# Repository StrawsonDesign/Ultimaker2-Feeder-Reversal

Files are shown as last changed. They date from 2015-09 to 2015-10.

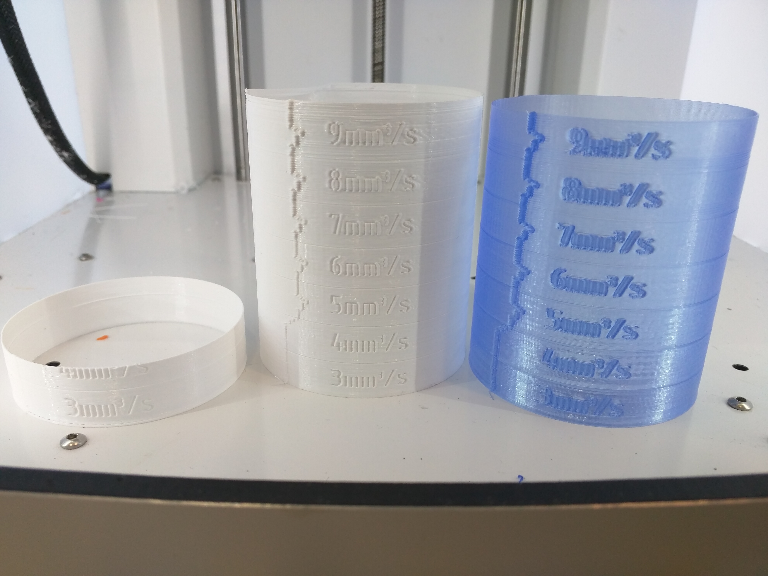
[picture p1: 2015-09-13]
Pictures/Speed_Improvement_Test.jpg

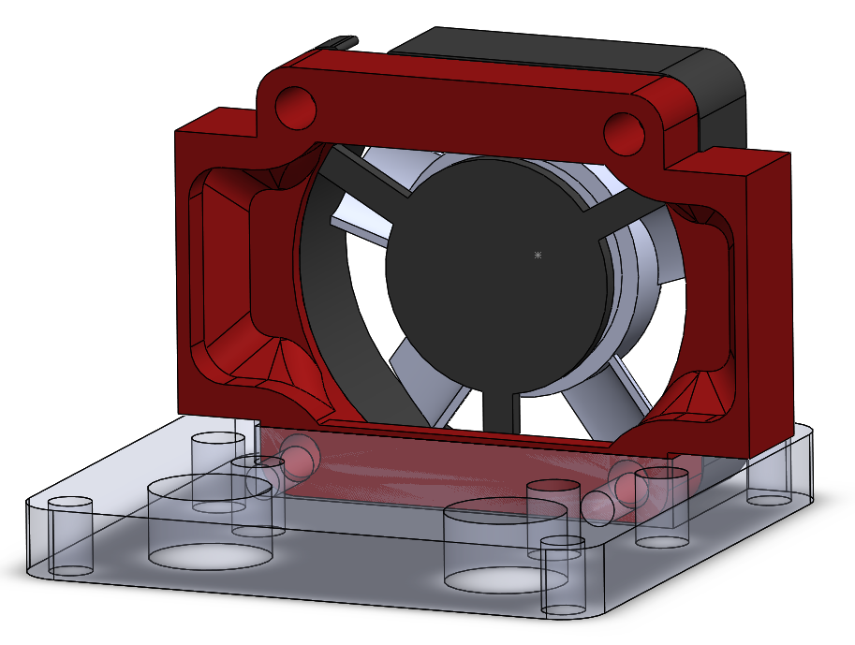
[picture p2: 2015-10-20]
Parts/Fan Duct/fan duct cad.PNG

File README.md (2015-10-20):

This repository contains all of the hardware and software modifications
we have made to our two Ultimaker 2 printers.

Included here is a fork of the Ultimaker 2 marlin firmware with the
necessary tweaks needed to complement the hardware tweaks.

See 'Ultimaker 2 Experiences and Modifications.pdf' for a detailed
outline of all the the modifications. The CAD files for the described
hardware mods are in this repository along with pictures of the
installation. 

See Strawson's 'Ultimaker Settings.fff' for the SImplify3D settings we
use with this configuration.

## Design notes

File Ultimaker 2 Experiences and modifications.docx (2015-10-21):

# Ultimaker 2 Experiences and Modifications

James Strawson 2015

University of California, San Diego

In April 2015 we took delivery of two brand new Ultimaker 2 desktop 3D printers to complement our overworked large-format printer. Our first impressions were positive. We enjoyed the clean user interface, solid construction, and especially the low-inertia X & Y axis mechanism. It is now October 2015 and we have put over 2000 hours of printing on each of them along with countless rebuilds. Along the way we have come to appreciate the many strengths of this design which have no-doubt been a result of the extensive testing and hacking of the original Ultimaker design by the open-source and DIY community. However, there are a couple of minor design faults which render the Ultimaker 2 unreliable and frustrating in a professional setting. Luckily these faults are cheap or free to remedy. In this paper we outline the various quibbles we have with the design of this printer and the steps we’ve taken to improve the performance and reliability. Along the way we will provide empirical test data to demonstrate the improvements along with discussion on our own failures along the way.

To help understand the component names used in this paper it is helpful to reference the Ultimaker 2 hardware documentation repository here https://github.com/Ultimaker/Ultimaker2.

## Thermal Improvements and Jamming

First I would like to start with a basic truth that explains the problems most people have when extruding PLA which has become the most popular plastic among the desktop 3D printer community. Within the hot end of every filament-fed FDM printer is a temperature gradient along the axis of the filament tube where the plastic transitions from solid to liquid. It is important that this gradient is as sharp as possible otherwise the filament will soften and expand under pressure to touch the inside of its guide tube. Usually this premature softening results in what we call jamming which is where the additional friction overcomes the feeder motor’s strength and plastic is no longer extruded consistently. In extreme cases the filament completely seizes in the hot end and must be melted out or forcefully removed. PLA suffers from jamming much more readily than ABS due to its lower melting temperature. This is not to be confused with clogging which is where a physical obstruction gets lodged in the small nozzle opening.

To keep this temperature gradient as sharp as possible, most hot ends employ active cooling in the form of a heatsink and fan right above the extruder nozzle and heater block. We have extensive experience with both the E3D V6 hot end and the Ultimaker 2 hot end, both of which have active cooling, and neither of which implement it properly. The E3D V6 includes a nicely designed heatsink with a ducted fan that ensures plenty of directed airflow over the heatsink fins. Sadly it is rendered mostly useless since the only surface contact the heatsink has with the heat break tube is a loose thread. The solution is simple: to fill the gaps of the thread with copious amounts of thermal paste. As an added measure we also heat up the aluminium heat sink with a hot air gun to about 150C before tightening the stainless steel heat break in place. When the heatsink cools it locks the threads tightly together preventing them from loosening during operation which would break what little thermal contact there is. I have added this procedure to the E3D wiki and have received considerable response from the online printing community confirming its effectiveness.

The Ultimaker 2 demonstrates the same thermal issue. About 40 minutes into a print we would consistently notice jamming and the part would be a complete failure. The problem is that the active cooling on the Ultimaker is not as active as you would think. The included 25mm 5V cooling fan is reasonably powerful, but is mounted flush against the heatsink in such a way that air is only allowed to flow through two of the eleven slots. To remedy this we designed a duct that spaces the fan 6mm back from the heatsink and allows airflow through all of the slots. This had the added bonus of reducing the noise generated by the fan for two reasons. Firstly the fan spins slightly slower based due to not being stalled from lack of airflow. Mostly the reduced noise is because the fan no longer rattles against the heatsink. The thermal performance gain from the duct immediately solved the jamming issue and we can now successfully complete >24 hour prints without overheating or jamming. The file for this duct is available on our GitHub repository linked at the end of this document.


The Ultimaker factory uses copper grease between what they call the hot end isolator and the hot end holder bottom mount. This is very wise for two reasons. Firstly it provides lubricant for this part when it is turned for adjustment, and secondly it provides a necessary thermal interface to transfer heat from the isolator to the heatsink. Without it, jamming will occur even with the cooling duct. Normal CPU thermal paste seems to work equally well and we suggest cleaning the interface and reapplying thermal paste every time the isolator is removed.

Once the heat has transferred from the hot end isolator to the bottom hot end holder, it must still transfer to the heatsink. However, the bottom of the heat sink is very rough on both of our models and looked to be machined with a dull end mill without a finishing pass. For good measure, we also applied thermal paste between the heatsink and the bottom hot end holder to improve this necessary thermal contact. We cannot confirm if there is a real performance improvement from this as the duct solved the jamming issue completely. However, thermal paste is cheap and application is easy since you must disassemble the hot end assembly to apply the remainder of these modifications anyway.

## Friction Reduction and Feeder Reversal

With the duct installed and thermal paste applied, you should finally be able to print larger parts without jamming. Sadly, you will also discover that printing any faster than 20mm/s at standard 0.1mm layer heights will result the feeder motor skipping steps. Regardless of how slowly we printed, we found that plastic would extrude very inconsistently and while parts may look alright, they would lack structural integrity and are therefore useless for engineering prototypes. This is what the Ultimaker community calls underextrusion which is caused by friction and rough passage of the filament through the Bowden tube while under pressure.

We give credit to YouMagine member Pikita for providing a volumetric speed test for the Ultimaker that slowly ramps up the extrusion rate from 3mm^3/s to 10mm^3/s to measure the limit of the printer. This part is available here https://www.youmagine.com/designs/test-print-for-ultimaker--2. There is also a lengthy community discussion here: https://ultimaker.com/en/community/view/5586-can-your-um2-printer-achieve-10mm3-s-test-it-here. From reading this thread we gather that factory-spec Ultimaker 2 printers vary greatly in the speed they can achieve and that many struggle to achieve 4mm^3/s even when running the hot end much hotter than normal at 230C. The creator of this test recommends running this test at a nozzle temperature of 230C but we find this a little unrealistic for PLA prints as that temperature will quickly cause plastic degradation and carbon buildup in the nozzle. We personally have found 210C to be the ideal PLA temperature on both our Ultimakers from the perspective of both extrusion consistency, layer bonding, and surface quality. However, neither of our Ultimakers could reliably extrude even 3mm^3/s at 210C so we kept with the recommended 230C for the time being.

As a quick experiment we added a thin coating of oil to the inside of the Bowden tube. Immediately the printer was able to extrude at 4mm^3/s. This slight but distinct improvement was evidence enough for us to pursue more permanent friction reduction methods. We do not recommend oiling the tube whatsoever as it quickly resulted in gunky buildup on the inside of the nozzle.

The standard feeder arrangement and spool holder places the knurled feeder wheel on the outside of the natural bend of the filament. Since the knurled feeder wheel is of particularly poor design it chews up the filament where it is in contact, especially if the part requires a lot of filament retractions. The filament twists such that its natural bend matches that of the Bowden tube. The friction of the chewed-up side of the filament against the inside of the entire feeder system when under pressure has proven to be the single largest contributor to poor performance. Luckily the entire filament assembly is reversible which places the smooth unmolested side of the filament in contact with the Bowden tube while under pressure.

All that is necessary is to remove the 2 M3 screws holding the left motor cover on and the 4 M3 screws holding the feeder mechanism to the back of the printer. After screwing the feeder mechanism back on in reverse, it is then necessary to reverse the direction of the feeder motor to compensate. This is a quick adjustment in software. At the end of this paper you will find a link to our GitHub repository with this and other necessary changes. With this change implemented, the friction of the filament through the entire mechanism was reduced so greatly that our volumetric speed test was now capable of printing 9mm^3/s at 230C, a threefold increase from the factory configuration. We confirmed this on both printers with both white and blue filament to be certain. Here are pictures of both the new feeder orientation and the new test pieces demonstrating the speed improvement.

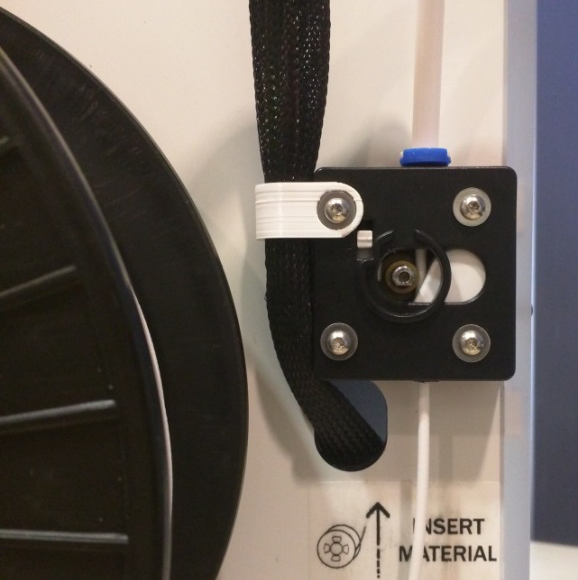
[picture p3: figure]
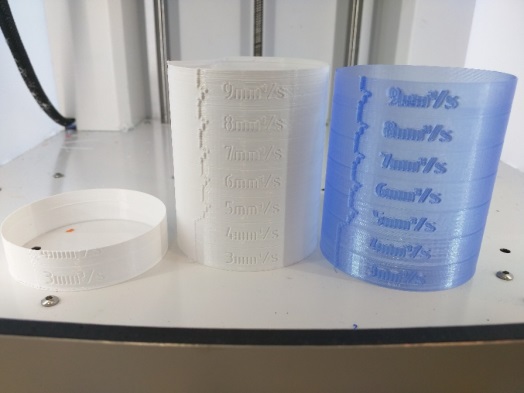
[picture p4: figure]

## Hobbed Wheel Upgrade

Even with this large reduction in friction, we wished to replace the poorly designed knurled feeder wheel with something that would both be less likely to grind straight through the filament and would reduce the slight slipping that results in inconsistent filament feed rate. We found that the hobbed feeder wheel design from the RepRap Mendel open source printer was a perfect fit on the Ultimaker 2 and resulted in much improved performance. This part is available from many sources on the internet, but we purchased ours from the Signwise here: http://www.amazon.com/gp/product/B00XP3NJSE?psc=1&redirect=true&ref_=oh_aui_detailpage_o01_s01.

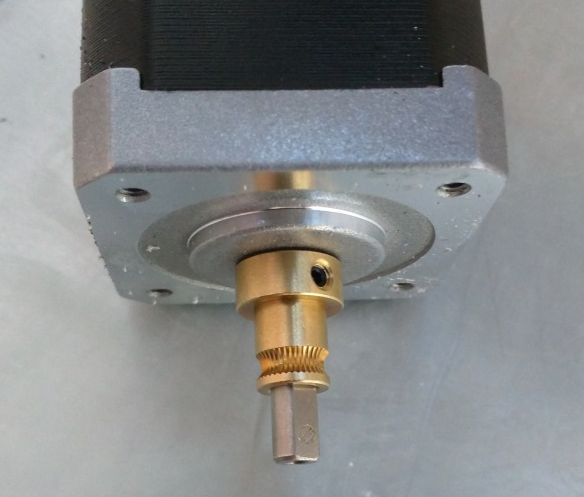
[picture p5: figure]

Instead of a sharp knurled surface which tends to wear away at the filament, this hobbed wheel actually wraps around the curvature of the filament providing much more surface contact and improved grip. Since it wraps around the contour of the filament it is possible to apply much more spring preload to the feeder bearing reducing the likelihood of slipping when the printer inevitably jams or clogs. We found that mounting it on the feeder motor shaft with 0.5mm clearance to the motor housing gave the correct offset to center the filament in the feeder mechanism. The above picture demonstrates correct mounting orientation.

The smaller diameter of the hobbed wheel means that it is necessary to run more spring preload in the feeder mechanism to achieve the same pressure. The Ultimaker manual suggests running as little preload as possible because any more will simply increase the rate at which the standard knurled feeder wheel chews through the filament. The hobbed wheel does not suffer from this problem and we can take advantage of higher pressure to reduce the chance of slipping. We have found that setting the preload at the second notch from the bottom is sufficient.

The new hobbed wheel measured 6.7mm diameter at its smallest point. The knurled wheel measured 7.9mm so we started by adjusting the steps/mm by the ideal ratio. The default is 282.

282*7.9/6.7 = 332.5 steps/mm

To test, we set the extrusion multiplier in our slicer to 1.00 and printed 20mm test cubes at solid infill to determine the exact steps/mm constant that gives us the best result. We did this process in parallel with both of our printers, one running undersized filament and the other running oversized filament. In both cases we did measure the filament diameter across a few points and entered this into the slicer. This tuning process is particularly important because there is less slip with this new feeder arrangement and slip is also a major contributor to the real-world feed ratio. The distance the knurling sinks into the filament and measurement error will make a difference. The ideal ratio of 332.5 was close, we experimentally found 327 steps/mm to give the best results on both printers and both filaments. The final change can be seen in our GitHub repository.

We were pleasantly surprised to see our experimentally determined steps/mm was within one percent of the calculated value. With the standard knurled wheel we had to run a 1.04 extrusion multiplier even when printing slowly and 1.08 when pushing as quickly as possible. With the new hobbed feeder wheel 1.00 gives us ideal results regardless of printing speed. This indicates considerable slip with the original feeder wheel.

## Increasing Feeder Motor Torque

The smaller diameter of the hobbed applies more linear force to the filament for the same feeder motor torque. The added grip of the hobbed wheel also allows us to increase the feeder motor torque without fear of chewing through the filament. Now we sought to achieve the highest feed extrusion rate possible while printing at the more realistic temperature of 210C since we almost hit the 10mm³/s limit at 230C.

When the Ultimaker 2 was first released the feeder current was set to 1350ma from the factory. A recent software update reduced that to 1250ma in an attempt to reduce the number of user complaints of chewed filament. We actually increase this to 1500ma to increase the total available torque available. Even at this higher current, the stepper will still skip as a failsafe before the hobbed wheel slips on the filament. While the stepper driver ICs are rated for 2000ma the Ultimaker control board is not designed with sufficient cooling and we hit the thermal protection safety at 1700ma.

We attempted to disable microstepping in hopes of gaining a bit more torque but this seems to be hardwired on the control board as firmware changes had no effect.

Before increasing the stepper current we were able to print 9mm3/s successfully at 230C but only 6mm/s at 210C. With the current increased to 1500ma and microstepping disabled we can now easily extrude 10mm3/s at both 230C and 220C. The 220C test pic pictured below on the left. Finally we can consistently extrude 8mm3/s at 210C as pictured below and on the right. Note that the 9mm3/s level is underextruded but still holds together without complete structural failure.

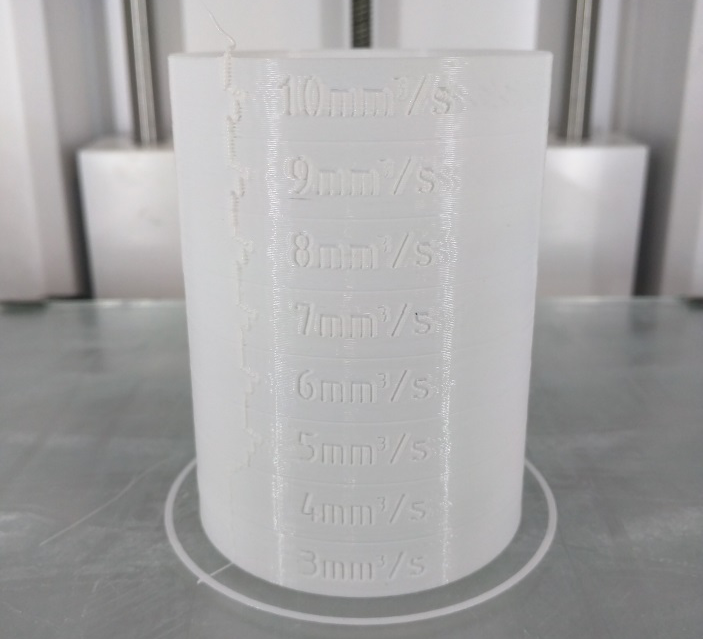
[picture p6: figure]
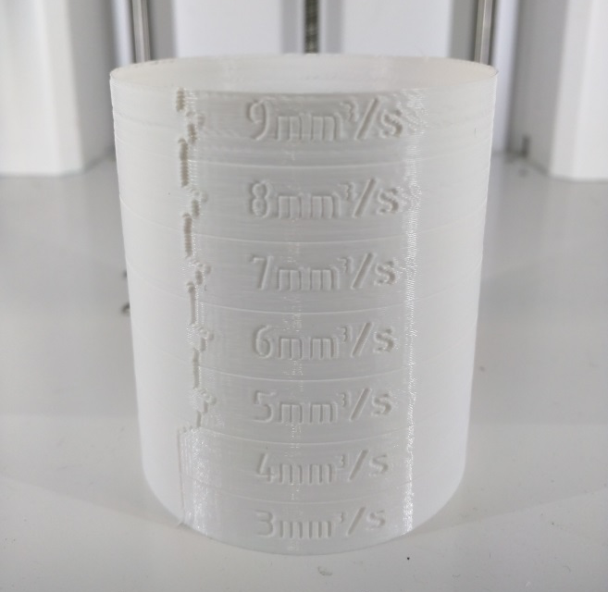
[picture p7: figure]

## Filament Guide and Spool Holder

During this tuning process we were also very careful to measure the filament diameter and make the appropriate change in our slicer settings for every test. We also noticed that the angle at which the filament entered the feeder make a slight difference as well as the bend radius of the filament. Thus, we pursued a filament guide setup that would provide more consistent results. The main improvement was installing a ball-bearing mounted spool just beneath the feeder mechanism using an existing hole that is used for the motor cover. In this convenient position the filament now feeds straight into the feeder mechanism instead of being tugged at an angle. While we were making improvements, we also made a second ball-bearing guide to replace the standard black plastic guide which had worn straight through as the filament simply grinds against it.

These spools are available on our GitHub along with the other components here. We designed them with a probably unnecessarily large flange to help keep the filament from slipping off when shifting the printers around or when the spool gets nudged. After two failed prints due to the filament slipping off the guide we arrived at this solution and have not had a single failure since.

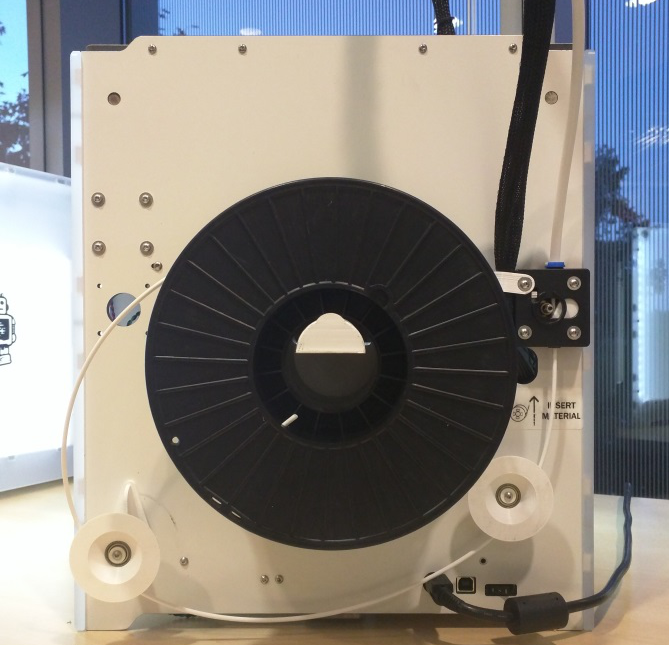
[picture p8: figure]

The standard spool holder also bothered us. Firstly it squeaked badly, and secondly its diameter was so large that most of our spools would not fit. YouMagine community member Solonari designed a very nice replacement that solves both of these problems as is available here: https://www.youmagine.com/designs/ultimaker-2-36mm-spool-holder-v1-2. We found that the small tab stopping the spool from sliding off was a little too small and broke easily so the version on our GitHub repository is strengthened.

YouMagine user Izzy also designed a nice clip to hold the Ultimaker wiring harness out of the way of the filament and the moving spool. There is no performance improvement to be had but it keeps the back of the Ultimaker neat and tidy and is well worth the 10 minutes it takes to print the part. It really bothers me that the wiring harness rubs against the filament from the factory. Reversing the feeder mechanism keeps this from happening but the harness still rubs on our larger spools so I highly suggest using Izzy’s design available here: https://www.youmagine.com/designs/wire-retainer-clip.

We only use one of these on each printer and mount it on the top left corner of the feeder mechanism when looking at the back of the printer. It can be seen in the previous pictures.

## Bowden Tube Replacement

We quickly discovered that the Ultimaker struggled to print in the back left corner of its print bed. This became very frustrating when printing large parts and batch prints. If one pays for a 23x22 cm bed then one should expect to be able to use all of it. The cause of this issue is that when printing in that far corner the Bowden tube is bent at a very tight radius. We sought to find a slightly longer tube which would be a drop in replacement and also provide less friction if possible.

Fluorotherm 1/8” ID PTFE tubing is a perfect fit for the Ultimaker Bowden clips. We ordered a 5 foot length and found that the 2.5 foot length achieved by cutting it in half was about 140mm longer than the Ultimaker Bowden tube. This was just enough added length to achieve consistent performance across the entire print bed and the tube has visibly less bend. Sliding the filament through by hand takes less effort than the standard Bowden tube also. This tubing is available here: http://www.amazon.com/gp/product/B00KJDE67G?psc=1&redirect=true&ref_=od_aui_detailpages01.

It is necessary to modify the tube stock slightly before installing it just like Ultimaker does. The feeder end needs to be countersunk at a 45 degree angle to allow new filament to feed in without catching on the edge when changing spools. It is also necessary to drill out the inside of the other end about 3cm deep with a 3/16” drill bit to prevent hot plastic from sticking to the inside when the printer retracts the filament after every print. We also beveled the outside edge of both ends of the tube to make inserting into the Bowden clips easier.

If your printer has been used a lot you may notice the tube has started to wobble in the clips slightly. The more play in the Bowden clips then the more retraction distance is necessary to both relieve the pressure off of the compressed filament and pull the filament back out of the nozzle slightly. The brand new tube should fit snuggly in the clips with zero movement up and down. The filament compresses significantly inside the tube when extruding quickly under pressure and the longer tube only increases this. Luckily the new hobbed feeder wheel allows us to use high retraction distances without chewing up the filament. We like to use 6.0mm of retraction and have found no reduction in stringiness by going higher.

The final modification that must be done to compensate for the longer tube is to increase the distance that the feeder pulls the filament out when changing filaments. This constant is called BOWDEN_FILAMENT_LENGTH in the firmware source code and we increased this distance from 705mm to 840mm in our GitHub Repository fork of the firmware.

## PTFE Isolator Coupler

About 500 hours into printing each of our Ultimakers demonstrated a sudden drop in performance. Furthermore, the filament would jam in the bowden tube after every print and would require manual removal and trimming. The reason for this is that the PTFE Isolator Coupler deforms over time from the heat of being in contact with the heater block. Ultimaker now consider this to be a wear item and charge $20 for a replacement.

Ultimaker community member Olsson designed and now sells a resilient insulator which installs between the heater block and the standard PTFE Isolator Coupler to extend the life of the coupler. This is called the I2K insulator as is available in Europe here: http://3dsolex.com/i2k-insulator. If you are in the US then community member GR5 sells these same parts at his store here: http://gr5.org/store/index.php/um/i2k-insulator.html. GR5 also sells the replacement isolator couplers for roughly half the price of the Ultimaker OEM replacement parts and they work equally well from our experience. GR5 is a helpful contributor to the Ultimaker 2 community and was one of the first people to be able to print at 10mm^3/s.

Olsson rightly suggests adjusting the height of the heater nozzle to be as high as possible by threading the steel hot end isolator all the way onto the heater block then backing off a quarter of a turn to prevent unnecessary thermal contact with the threads. This puts as much spring pressure as possible on the PTFE Coupler and I2K Insulator to prevent leaking. It also raises the PTFE coupler higher up into colder region of steel hot end isolator to reduce its temperature and make the part last longer. This may also serve to increase the temperature gradient as discussed in the thermal section of this paper but this is difficult to measure. Another benefit it that this prevents the heater block from touching the steel cooling fan duct which ours did from the factory. In addition to the loss in efficiency, we also found that the nozzle would drop in temperature by over 10 degrees as soon as the cooling fans turned on before the feedback controller brought it back up. With the added clearance this no longer occurs.

## Nozzle Cleaning

Every time we change filament colour we perform a cold pull to clean out the nozzle. We will also do this before rebuilding the hot end to remove all traces of plastic from the PTFE isolator coupler and the heater block. We credit the procedure to Ultimaker forum member MostlyAtomicBob and is well documented here: https://ultimaker.com/nl/support/view/149-atomic-method. For the Ultimaker, our exact procedure is as follows:

1. Remove the Bowden tube from the top of the hot end.
2. Manually set the nozzle temperature to 210C in the Ultimaker 2 advanced menu.
3. Insert a piece of scrap white PLA into the nozzle which is at least 300mm long.
4. Press the filament in firmly and extrude about 40mm of filament to flush out old plastic.
5. Set the temperature to 75C and keep pushing filament through as it cools.
6. At around 110C the chance of air getting in is minimal and you can let go while it keeps cooling.
7. After it has settled at 75C for a couple minutes, tug the filament out quickly.
8. Make sure the hot end isolator has seated back into its groove in the bottom hot end holder. If it hasn’t, wiggle it back into place with a 2.5mm hex key.
9. If the white PLA pulled out a significant amount of black crud from the inside of the nozzle then repeat the process.

Turning the knob continuously to set the temperature can be rather annoying. YouMagine member Swonkie has designed a fantastic replacement knob available here: https://www.youmagine.com/designs/ultimaker-2-knob--2. This is a very nice touch to the printer and makes removing the knob easy if you want to keep people from fiddling with it during a print such as at trade shows.

## Retraction and Wipe Setting

With less play due to the nice new bowden tube we wished to retune the retraction distance that is just enough to stop stringiness. For this test we printed in parallel a 20mm cube along with nine 4x4x20mm columns so there would be plenty of retractions along with big and small islands to make sure extrusion was consistent across the whole print bed.

We started with the retraction settings that worked well for us with the default configuration: 6mm retraction, 0.5mm coast, and 2mm wipe. This was done using Simplify3D 3.0.2 for our slicer. We actually found that only 3mm retraction was now sufficient. Since Simplify3D now supports gentle retraction while wiping we increased the wipe to 3mm so the print head wouldn’t need to slow down as much for the wipe. We then quickly discovered that prints would underextrude in areas with multiple islands. Disabling the coast feature helped this slightly as plastic no longer stops extruding right at the end of each loop. The result was that all 9 thin columns and the 20mm cube would print completely solid with no skipped layers and each stood up to a quick bend test by hand. Previously parts with skipped layers would simply fall apart in your hand.

We finally discovered that while that test print worked perfectly, other real parts would still cause extruder jamming and underextrusion in areas with lots of islands. This appears to be a bug with simplify3D 3.0.2 as reported here https://forum.simplify3d.com/viewtopic.php?f=9&t=3536. The solution was to check the box for relative extrusion.

## Software Changes

The following software settings changes were necessary:

- Reverse feeder motor direction on line 325 of Configuration.h

#define INVERT_E0_DIR true

- Increase feeder motor current to 1450ma on line 207 of Configuration_adv.h

#define DEFAULT_PWM_MOTOR_CURRENT {1200, 1200, 1500}

- Change feeder motor steps/mm on line 366 of Configuration.h

#define DEFAULT_AXIS_STEPS_PER_UNIT {80.0,80.0,200,327}

- Increase retraction length when changing filaments on line 385 of Configuration.h

#define FILAMANT_BOWDEN_LENGTH 840

Much to our frustration we found that the feeder motor current and motor steps/mm are read in from the EEPROM on startup instead of from the firmware binary itself. Only after performing a factory reset do these changes take effect. Since we wished to flash new Ultimakers in one step we also added the following lines to the very end of the Config_RetrieveSettings() function at line 241 of ConfigurationStore.cpp to ignore what’s in EEPROM and load our new default settings instead.

//ignore EEPROM extruder steps/mm and current

float temp1[]=DEFAULT_AXIS_STEPS_PER_UNIT;

axis_steps_per_unit[3]=temp1[3]; //overide EEPROM steps

float temp2[]=DEFAULT_PWM_MOTOR_CURRENT;

motor_current_setting[2] = temp2[2]; // overide EEPROM current

## Failed Experiments

We have tried a couple of unsuccessful modifications which we would like to share with you here anyway. Our first attempt at fixing the underextrusion issues was to try the very popular replacement feeder by YouMagine user IRobertI here:https://www.youmagine.com/designs/alternative-um2-feeder-version-two.

It is nicely designed and we loved that it includes a quick release to pull the feeder bearing away and allow manual removal of the filament when the knurled feeder wheel grinds through the filament or gets jammed. However, it doesn’t offer any performance improvement nor does it address the fundamental problem with the feeder which is the knurled wheel itself. It also cannot be installed in reverse which is what helped us reduce the friction in the Bowden tube.

We also tried the fan ducts designed by YouMagine user mnis available here: https://www.youmagine.com/designs/ultimaker-2-cpv9. We loved that it allows you to throw away the 12 screws holding the cooling fans and the original duct in place which makes rebuilding the hot end much faster. We also love that it directs some of the cooling flow to the heat sink and the PTFE coupler which actually works so well that our previously discussed heat sink cooling duct was not necessary. In addition, the fans stick out less giving a few more millimeters of useable print bed on the right side. However, there are two issues. The small amount of plastic which is purged out at the beginning of every print is prone to getting caught in the ducts whereas the factory duct knocks that plastic off the side of the bed. More critically, when printed out of PLA these ducts tend to warp and sag after a couple hundred hours of printing. This was a neat experiment but there is really no reason to change the OEM cooling fan arrangement.

## Conclusion

To summarize we made the following hardware modifications in order of importance:

- Printed fan duct
- Feeder mechanism reversal
- New hobbed feeder wheel
- I2K insulator
- PTFE Bowden tube
- Ball bearing filament guide spools
- Thermal paste on heatsink and isolator
- Printed spool holder
- Printed control knob
- Printed wire clip

The combination of these small improvements has entirely fixed our complaints with the original Ultimaker 2 design. It can now extrude plastic over 3 times faster and with more consistency. Furthermore it is quieter when in operation and has not jammed or stripped the filament once since the modifications. Finally, we do not need to replace the PTFE coupler once every 6 weeks. None of these modifications were expensive or difficult, however the process was tedious and time consuming. We hope you, fellow Ultimaker 2 owner, can benefit from what we have documented here. We also thank Ultimaker for what we still consider to be one of the highest quality printers on the market but with the hope that these simple changes make their way into the OEM assembly procedure.

The CAD files and complete firmware source code required for the modifications documented here are all available here: https://github.com/StrawsonDesign/Ultimaker2_Mods

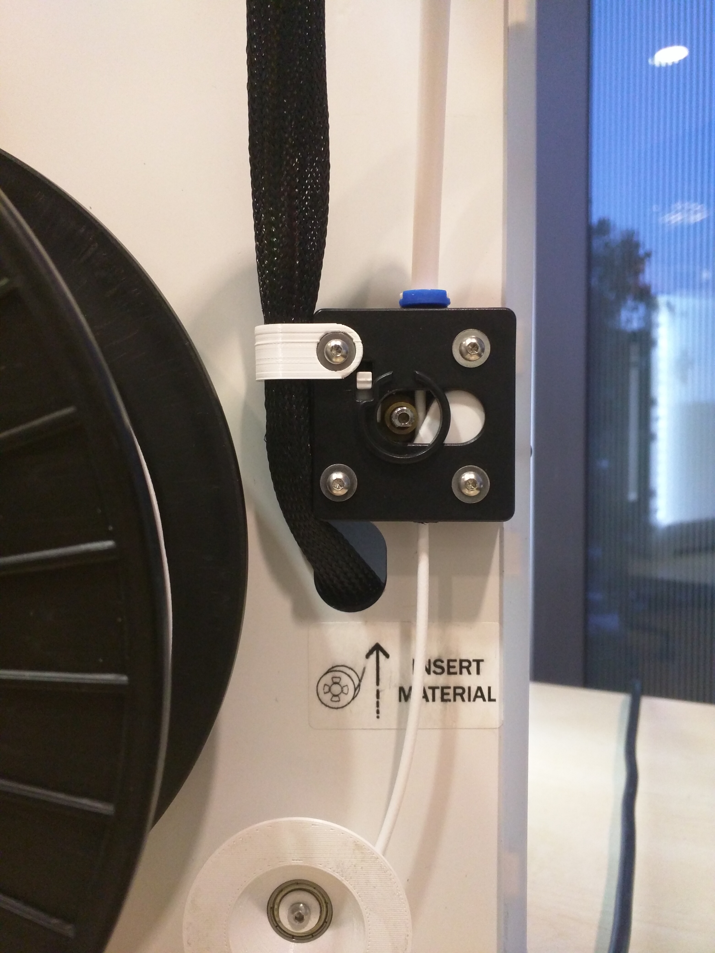
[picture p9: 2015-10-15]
Pictures/Feeder_Orientation.jpg

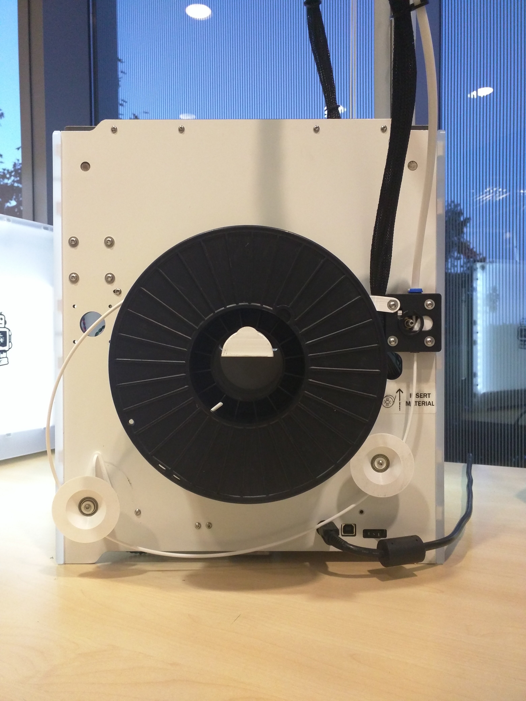
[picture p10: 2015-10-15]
Pictures/Ball_Bearing_Spools.jpg

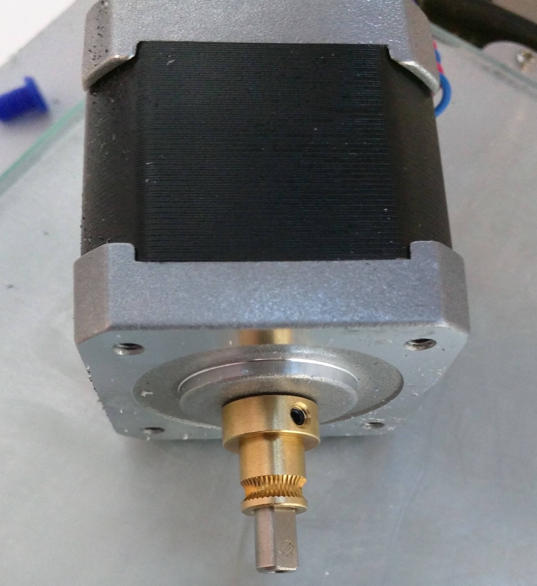
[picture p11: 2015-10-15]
Pictures/Hobbed_Feeder_Wheel.jpg

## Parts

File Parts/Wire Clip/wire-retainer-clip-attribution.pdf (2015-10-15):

# Wire Retainer Clip

by

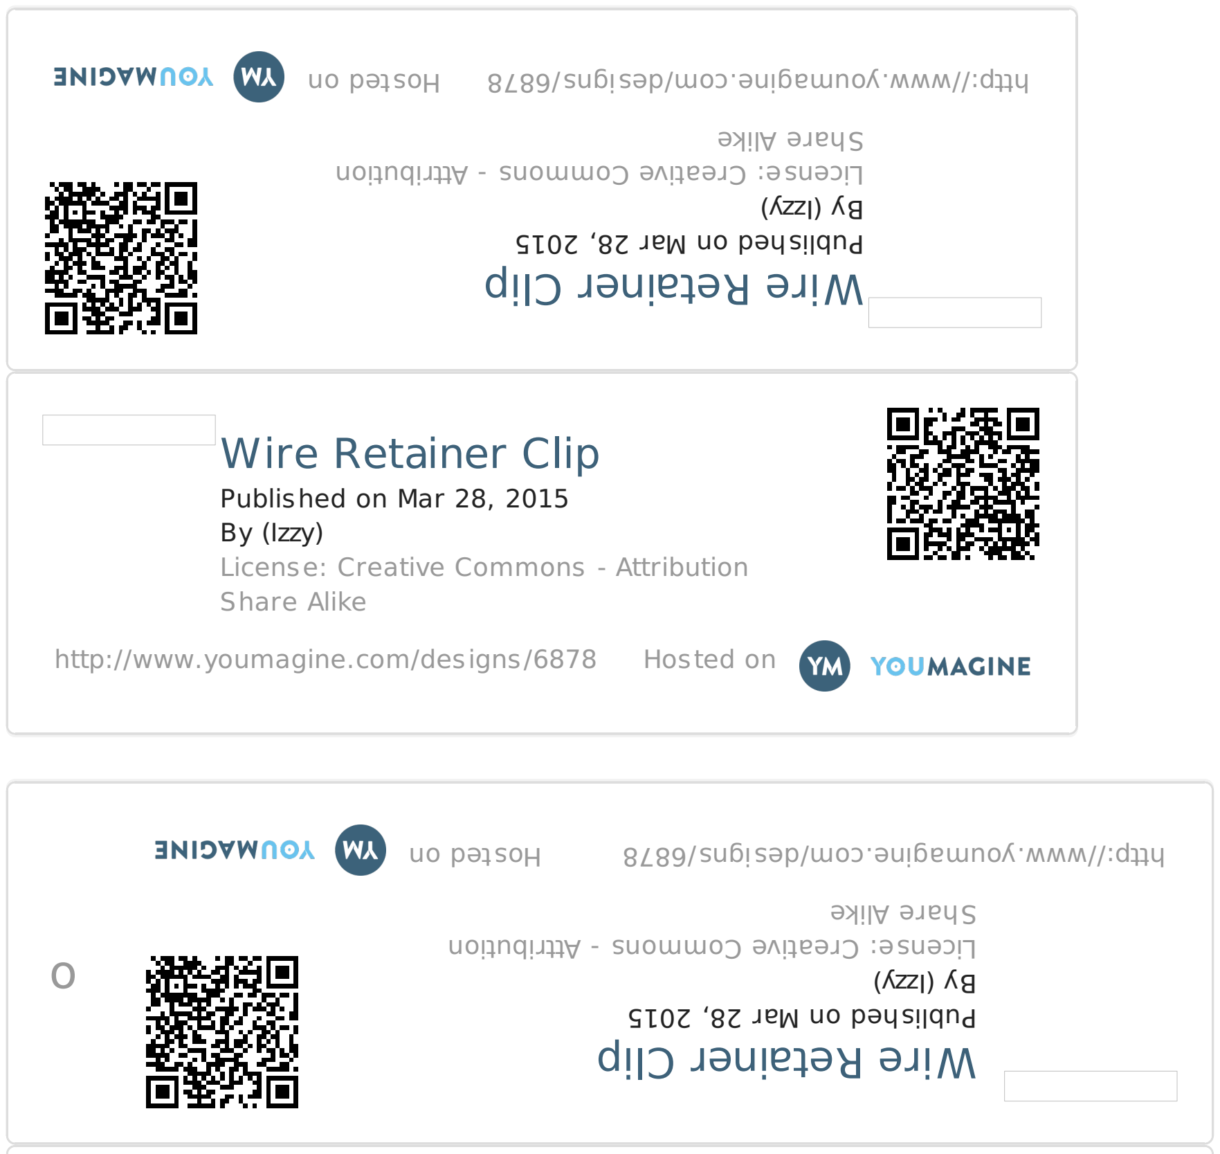
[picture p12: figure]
Wire Retainer Clip; Published on Mar 28, 2015 By (Izzy) License: Creative Commons - Attribution Share Alike; http://www.youmagine.com/designs/6878; Hosted on

o

## Wire Retainer Clip

Published on Mar 28, 2015
By (Izzy)
License: Creative Commons - Attribution Share Alike

http://www.youmagine.com/designs/6878 Hosted on

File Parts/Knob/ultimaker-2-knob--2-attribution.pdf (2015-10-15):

# Ultimaker 2 Knob

## By Swonkie

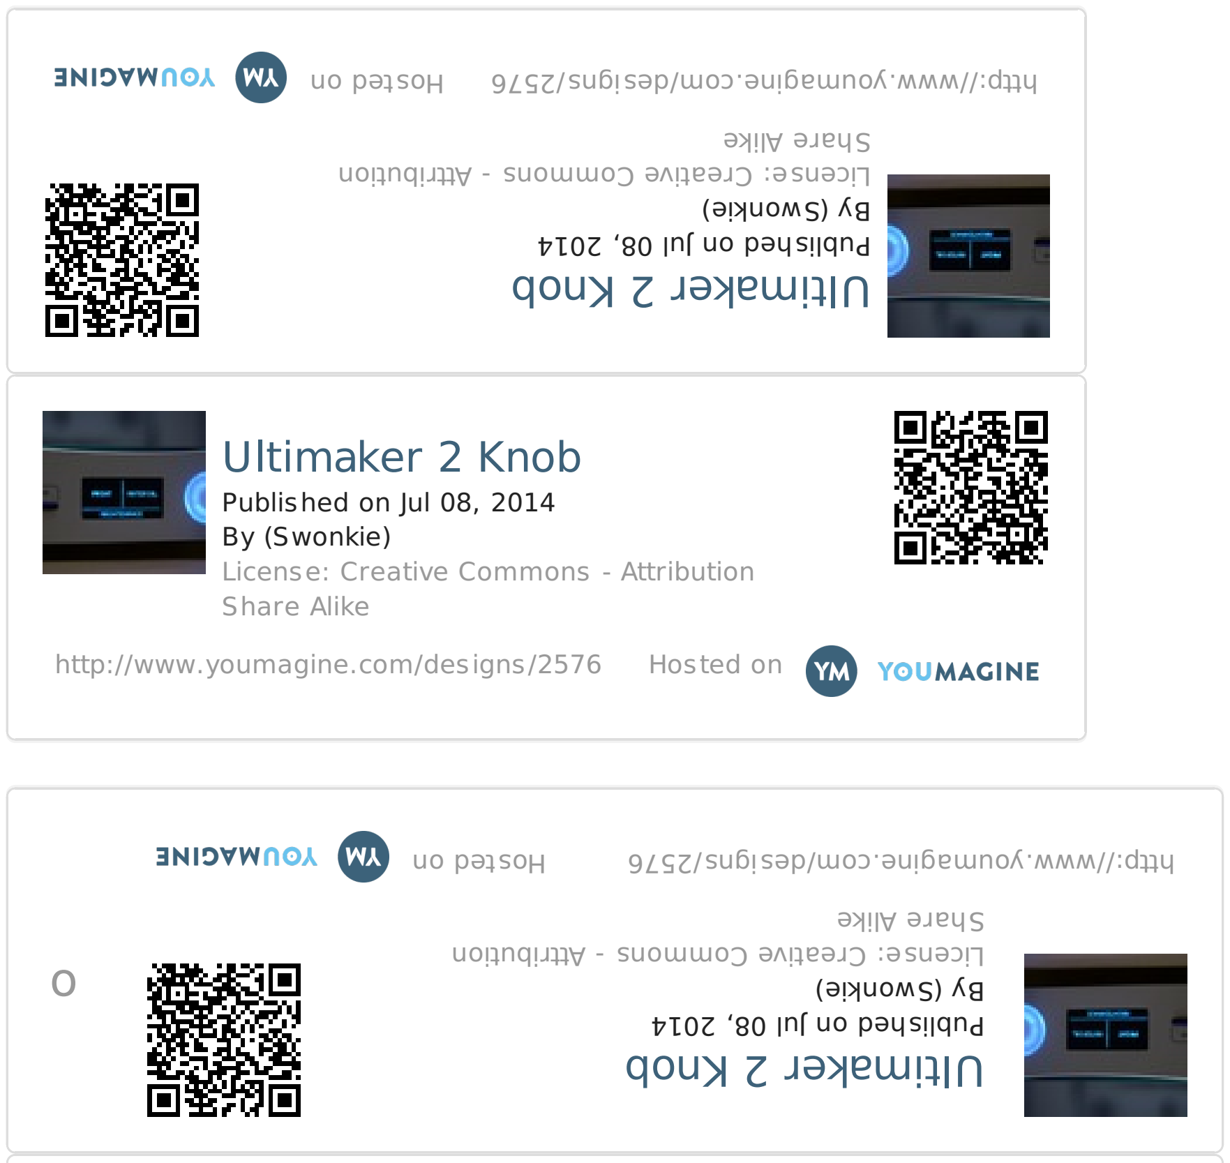
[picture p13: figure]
Ultimaker 2 Knob; Published on Jul 08, 2014 By (Swonkie) License: Creative Commons - Attribution Share Alike; http://www.youmagine.com/designs/2576; Hosted on

o

## Ultimaker 2 Knob

Published on Jul 08, 2014
By (Swonkie)
License: Creative Commons - Attribution Share Alike

http://www.youmagine.com/designs/2576 Hosted on

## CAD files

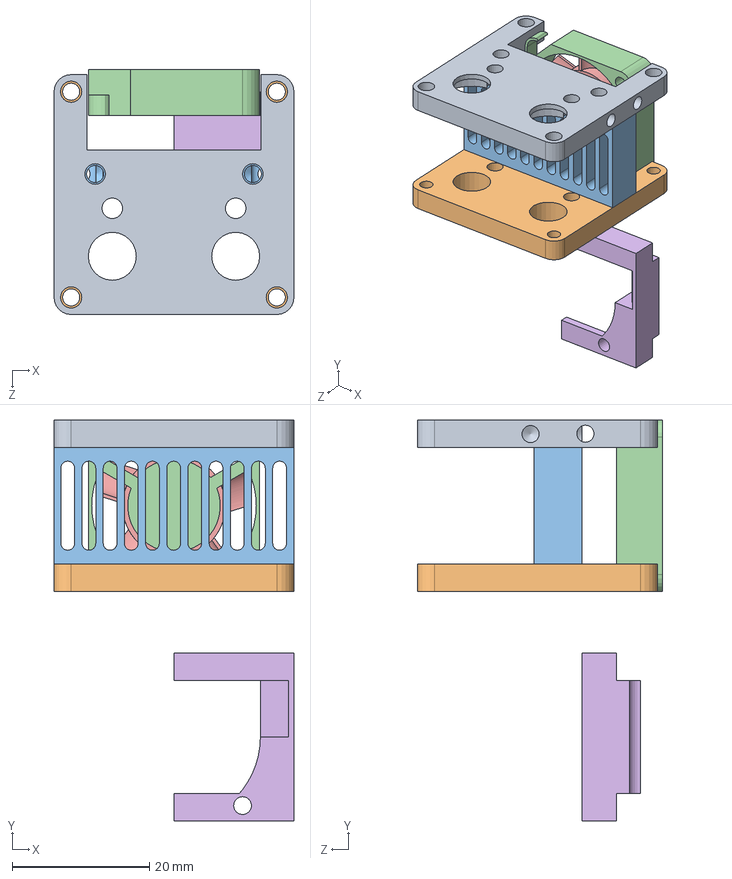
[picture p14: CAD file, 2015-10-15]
Parts/Fan Duct/solidworks assembly/fan duct assembly.SLDASM
35.0 x 58.5 x 35.8 mm
1307-Z2P-B Hot End Holder Top
1306-Z2P-B hot end holder bottom
1308-Z2P-B Cooling Rib Hot End
1330 Fan Base 25x25
DUct

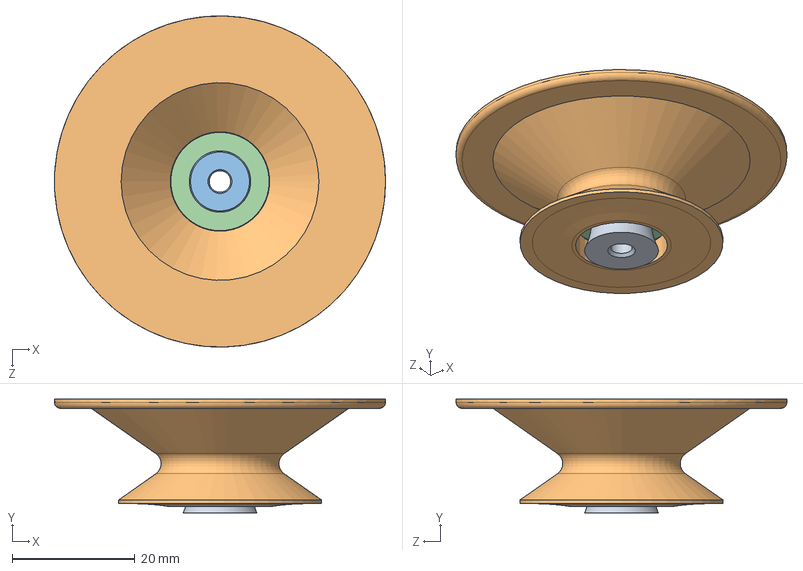
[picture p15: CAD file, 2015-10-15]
Parts/Bearing Filament Guides/Assem1.SLDASM
53.9 x 18.5 x 53.9 mm
standoff
outer guide
washer
bearing

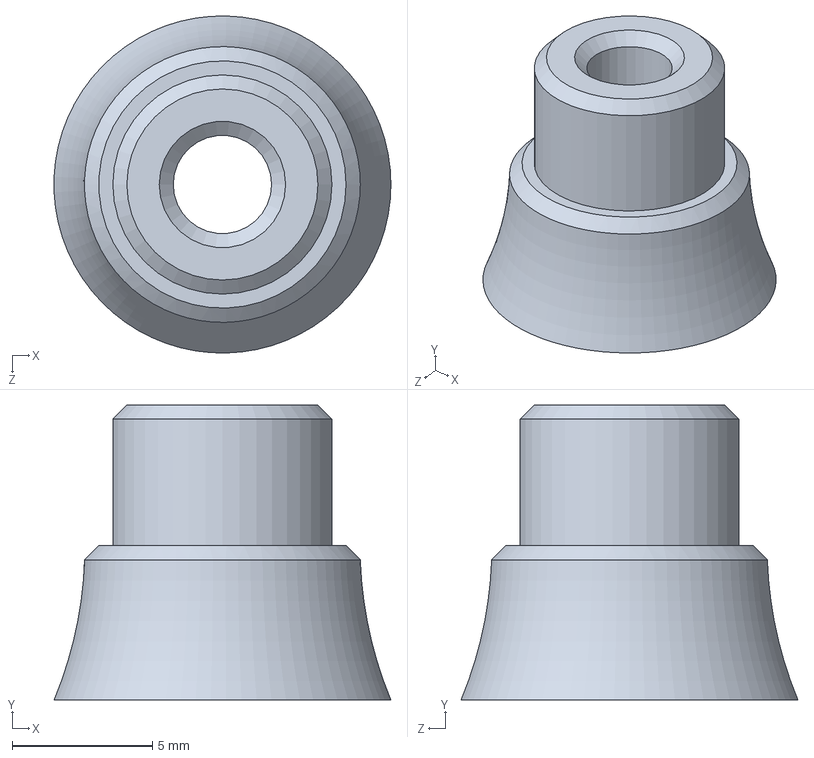
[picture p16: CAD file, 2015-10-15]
Parts/Bearing Filament Guides/standoff.SLDPRT
12.0 x 10.5 x 12.0 mm

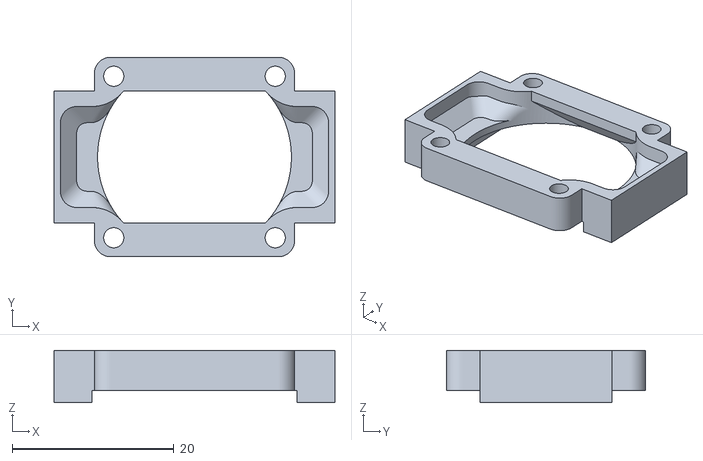
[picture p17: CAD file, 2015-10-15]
Parts/Fan Duct/Duct.STL
34.8 x 24.7 x 6.50

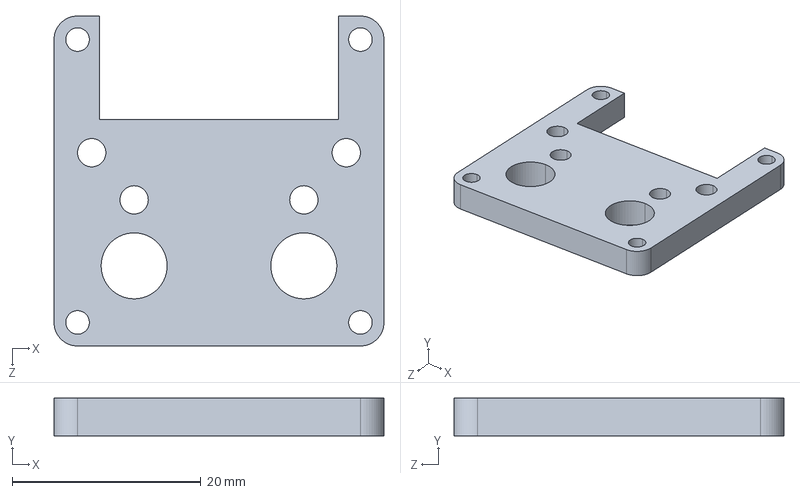
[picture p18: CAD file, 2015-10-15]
Parts/Fan Duct/solidworks assembly/1306-Z2P-B hot end holder bottom.STEP
35.0 x 4.00 x 35.0 mm

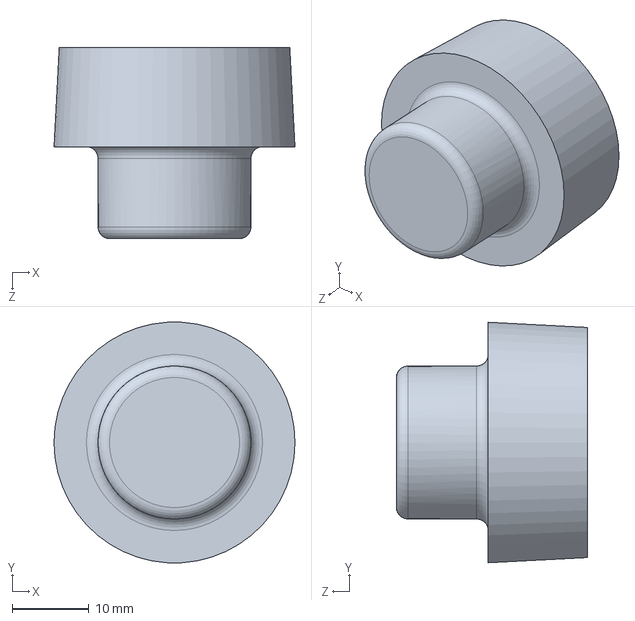
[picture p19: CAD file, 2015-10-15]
Parts/Knob/Knob.SLDPRT
31.5 x 31.4 x 25.0 mm

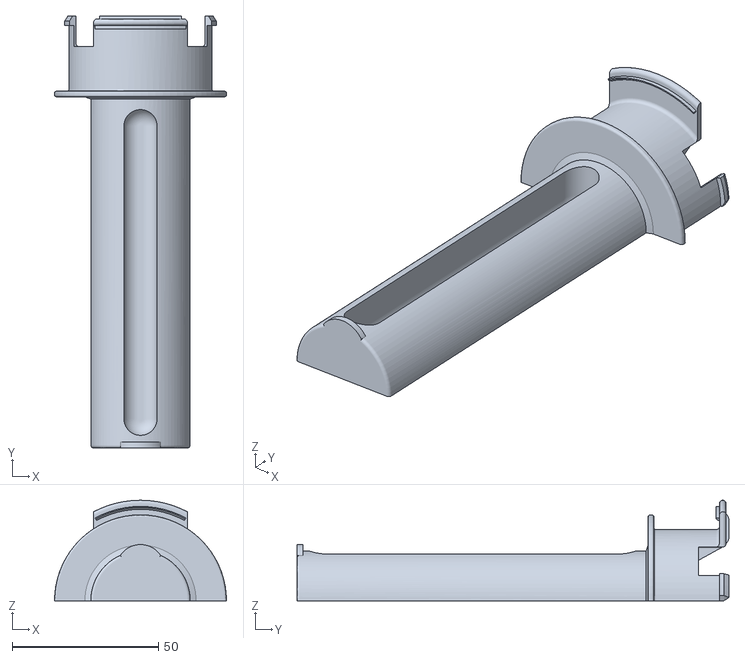
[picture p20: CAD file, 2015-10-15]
Parts/Spool Holder/Filament_Spool_Holder_v1_2 JS.STL
58.8 x 147.7 x 34.4

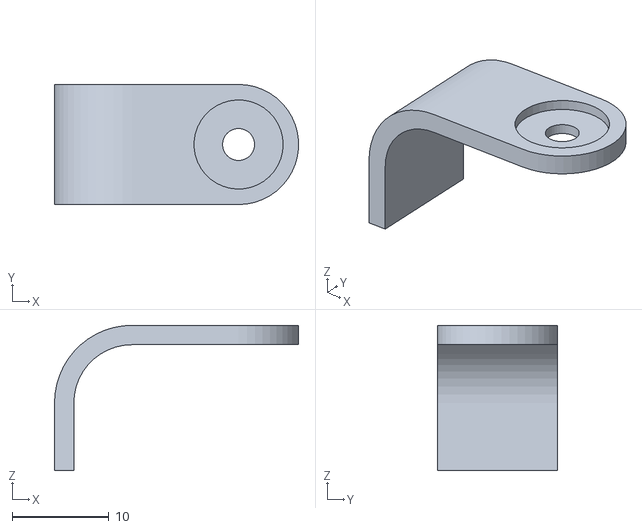
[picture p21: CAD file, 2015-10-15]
Parts/Wire Clip/Wire_Retainer_Clip.STL
25.2 x 12.4 x 15.0

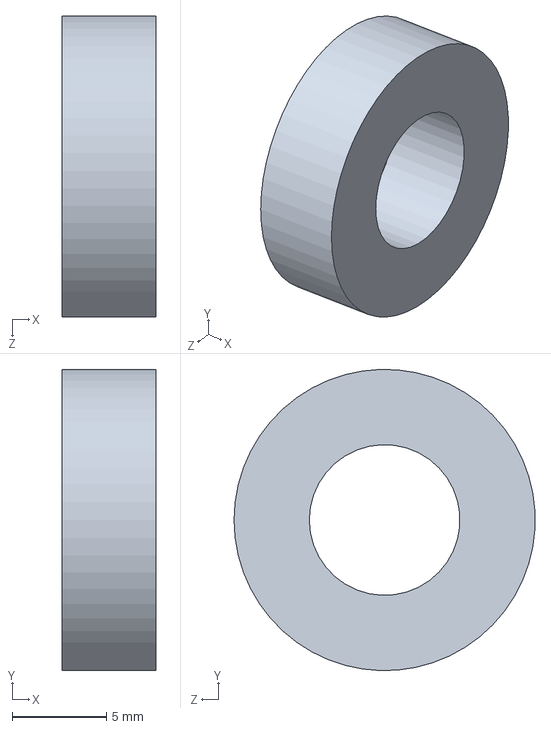
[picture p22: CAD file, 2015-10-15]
Parts/Bearing Filament Guides/bearing.SLDPRT
5.00 x 16.0 x 16.0 mm

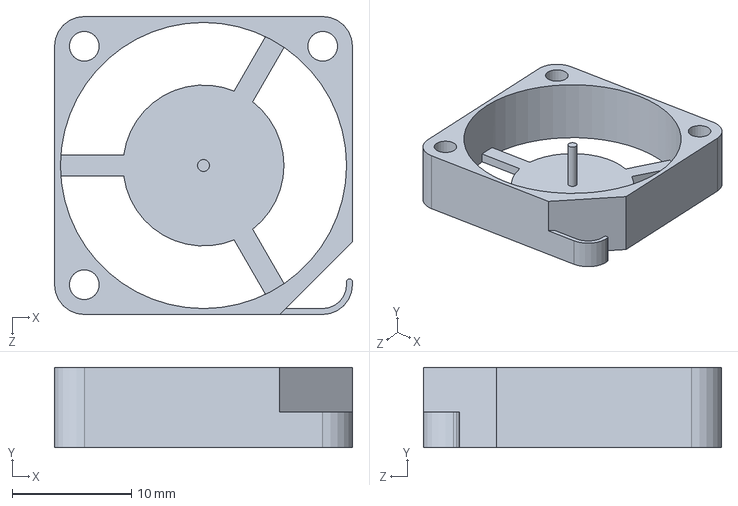
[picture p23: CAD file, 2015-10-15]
Parts/Fan Duct/solidworks assembly/1330 Fan Base 25x25.sldprt
25.0 x 6.75 x 25.0 mm

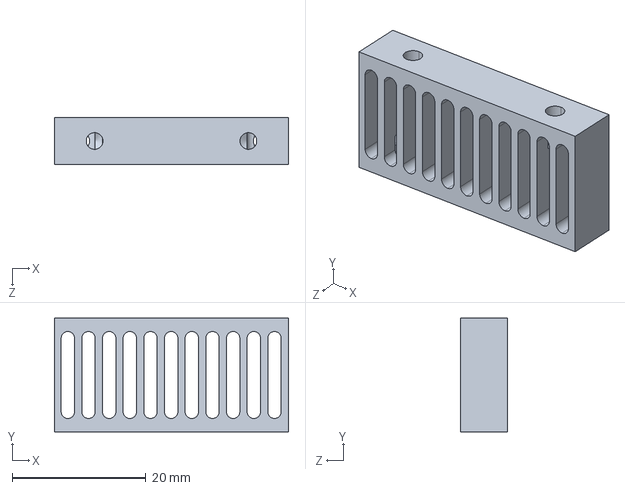
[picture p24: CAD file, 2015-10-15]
Parts/Fan Duct/solidworks assembly/1308-Z2P-B Cooling Rib Hot End.STEP
35.0 x 17.0 x 7.00 mm

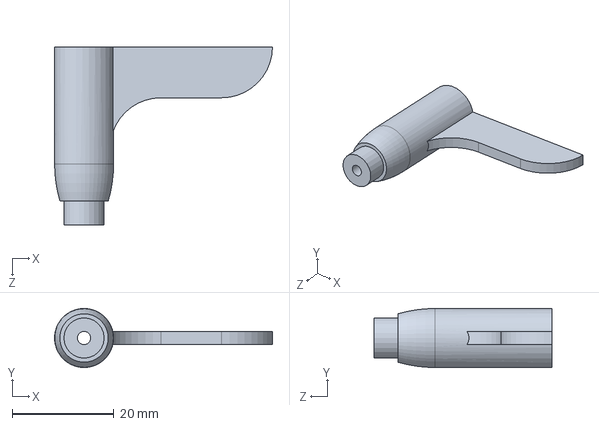
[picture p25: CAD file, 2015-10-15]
Parts/Bearing Filament Guides/shaft.SLDPRT
42.8 x 11.6 x 35.0 mm

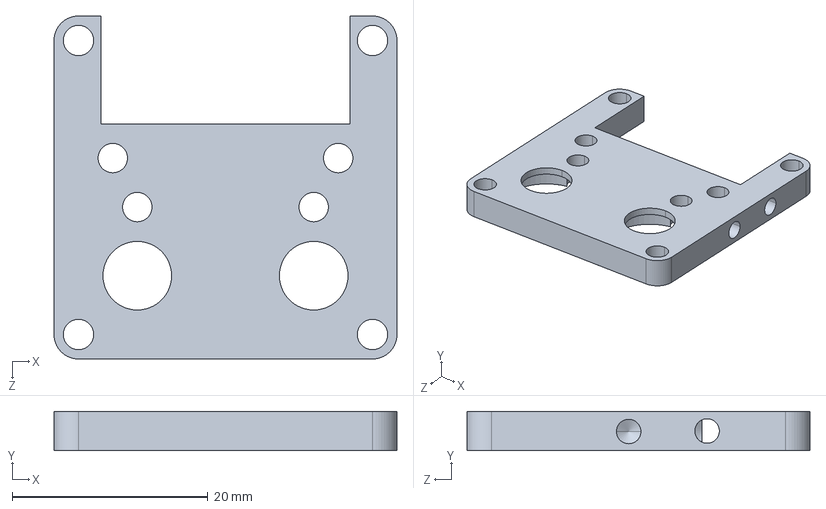
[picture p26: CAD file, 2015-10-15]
Parts/Fan Duct/solidworks assembly/1307-Z2P-B Hot End Holder Top.STEP
35.0 x 4.00 x 35.0 mm

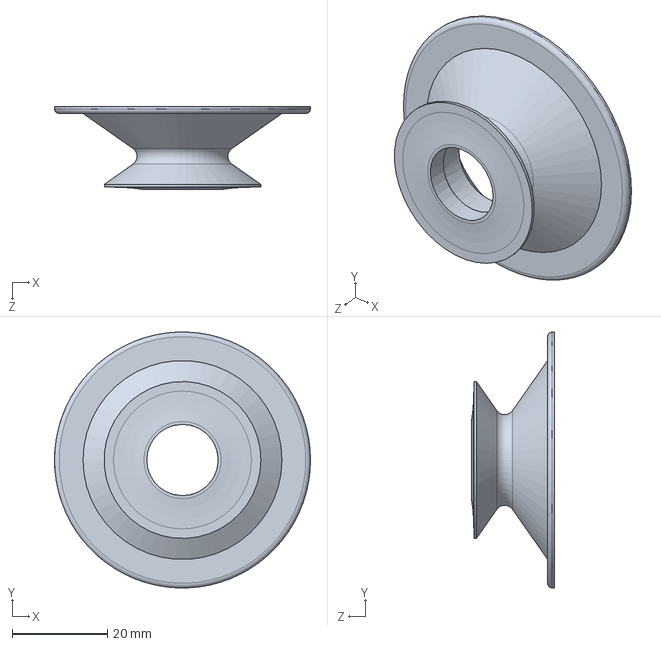
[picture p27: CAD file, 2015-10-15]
Parts/Bearing Filament Guides/outer guide.SLDPRT
53.8 x 53.8 x 17.5 mm

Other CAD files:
Parts/Fan Duct/solidworks assembly/1329-B2P-C Dual Fan Bracket.STEP
Parts/Bearing Filament Guides/Clip.stl
Parts/Fan Duct/solidworks assembly/1330-Z1P-B Cooling Fan.STEP
Parts/Fan Duct/solidworks assembly/1330 Fan Rotor 25x25.sldprt
Parts/Bearing Filament Guides/outer guide.STL
Parts/Bearing Filament Guides/shaft.STL
Parts/Bearing Filament Guides/standoff.STL
Parts/Bearing Filament Guides/washer.SLDPRT
Parts/Bearing Filament Guides/washer.STL
Parts/Fan Duct/solidworks assembly/1306-Z2P-B hot end holder bottom.SLDPRT
Parts/Fan Duct/solidworks assembly/1307-Z2P-B Hot End Holder Top.SLDPRT
Parts/Fan Duct/solidworks assembly/1308-Z2P-B Cooling Rib Hot End.SLDPRT
Parts/Fan Duct/solidworks assembly/1329-B2P-C Dual Fan Bracket.SLDPRT
Parts/Fan Duct/solidworks assembly/1330-Z1P-B Cooling Fan.SLDASM
Parts/Fan Duct/solidworks assembly/Duct.SLDPRT
Parts/Knob/Knob.STL

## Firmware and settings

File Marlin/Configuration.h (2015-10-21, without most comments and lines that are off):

#define CONFIGURATION_H
#define STRING_VERSION_CONFIG_H __DATE__ " " __TIME__ // build date and time
#define STRING_CONFIG_H_AUTHOR "Version DEV" // Who made the changes.
#define SERIAL_PORT 0
#define BAUDRATE 250000
#define MOTHERBOARD 72
#define EXTRUDERS 1
#define POWER_SUPPLY 2
#define DELTA_SEGMENTS_PER_SECOND 200
#define DELTA_DIAGONAL_ROD 250.0 // mm
#define DELTA_SMOOTH_ROD_OFFSET 175.0 // mm
#define DELTA_EFFECTOR_OFFSET 33.0 // mm
#define DELTA_CARRIAGE_OFFSET 18.0 // mm
#define DELTA_RADIUS (DELTA_SMOOTH_ROD_OFFSET-DELTA_EFFECTOR_OFFSET-DELTA_CARRIAGE_OFFSET)
#define SIN_60 0.8660254037844386
#define COS_60 0.5
#define DELTA_TOWER1_X -SIN_60*DELTA_RADIUS // front left tower
#define DELTA_TOWER1_Y -COS_60*DELTA_RADIUS
#define DELTA_TOWER2_X SIN_60*DELTA_RADIUS // front right tower
#define DELTA_TOWER2_Y -COS_60*DELTA_RADIUS
#define DELTA_TOWER3_X 0.0 // back middle tower
#define DELTA_TOWER3_Y DELTA_RADIUS
#define TEMP_SENSOR_0 20
#define TEMP_SENSOR_1 20
#define TEMP_SENSOR_2 0
#define TEMP_SENSOR_BED 20
#define MAX_REDUNDANT_TEMP_SENSOR_DIFF 10
#define TEMP_RESIDENCY_TIME 3   // (seconds)
#define TEMP_HYSTERESIS 3       // (degC) range of +/- temperatures considered "close" to the target one
#define TEMP_WINDOW     2       // (degC) Window around target to start the residency timer x degC early.
#define HEATER_0_MINTEMP 5
#define HEATER_1_MINTEMP 5
#define HEATER_2_MINTEMP 5
#define BED_MINTEMP 5
#define HEATER_0_MAXTEMP 275
#define HEATER_1_MAXTEMP 275
#define HEATER_2_MAXTEMP 275
#define BED_MAXTEMP 200
#define MAX_HEATING_TEMPERATURE_INCREASE 10
#define MAX_HEATING_CHECK_MILLIS (30 * 1000)
#define PIDTEMP
#define BANG_MAX 255 // limits current to nozzle while in bang-bang mode; 255=full current
#define PID_MAX 255 // limits current to nozzle while PID is active (see PID_FUNCTIONAL_RANGE below); 255=full current
  #define PID_FUNCTIONAL_RANGE 1000 // If the temperature difference between the target temperature and the actual temperature
  #define PID_INTEGRAL_DRIVE_MAX 255  //limit for the integral term
  #define K1 0.99 //smoothing factor within the PID
  #define PID_dT ((OVERSAMPLENR * 4.0)/(F_CPU / 64.0 / 256.0)) //sampling period of the temperature routine
    #define  DEFAULT_Kp 10.0
    #define  DEFAULT_Ki 2.5
    #define  DEFAULT_Kd 100.0
#define MAX_BED_POWER 255 // limits duty cycle to bed; 255=full current
#define PREVENT_DANGEROUS_EXTRUDE
#define PREVENT_LENGTHY_EXTRUDE
#define EXTRUDE_MINTEMP 170
#define EXTRUDE_MAXLENGTH 1000.0 //prevent extrusion of very large distances.
#define ENDSTOPPULLUPS // Comment this out (using // at the start of the line) to disable the endstop pullup resistors
  #define ENDSTOPPULLUP_XMAX
  #define ENDSTOPPULLUP_YMAX
  #define ENDSTOPPULLUP_ZMAX
  #define ENDSTOPPULLUP_XMIN
  #define ENDSTOPPULLUP_YMIN
  #define ENDSTOPPULLUP_ZMIN
const bool X_ENDSTOPS_INVERTING = true; // set to true to invert the logic of the endstops.
const bool Y_ENDSTOPS_INVERTING = true; // set to true to invert the logic of the endstops.
const bool Z_ENDSTOPS_INVERTING = true; // set to true to invert the logic of the endstops.
#if defined(COREXY) && !defined(DISABLE_MAX_ENDSTOPS)
  #define DISABLE_MAX_ENDSTOPS
#endif
#define X_ENABLE_ON 0
#define Y_ENABLE_ON 0
#define Z_ENABLE_ON 0
#define E_ENABLE_ON 0 // For all extruders
#define DISABLE_X false
#define DISABLE_Y false
#define DISABLE_Z false
#define DISABLE_E false // For all extruders
#define INVERT_X_DIR true     // for Mendel set to false, for Orca set to true
#define INVERT_Y_DIR false    // for Mendel set to true, for Orca set to false
#define INVERT_Z_DIR true     // for Mendel set to false, for Orca set to true
#define INVERT_E0_DIR true   // for direct drive extruder v9 set to true, for geared extruder set to false
#define INVERT_E1_DIR true    // for direct drive extruder v9 set to true, for geared extruder set to false
#define INVERT_E2_DIR false   // for direct drive extruder v9 set to true, for geared extruder set to false
#define X_HOME_DIR -1
#define Y_HOME_DIR 1
#define Z_HOME_DIR 1
#define min_software_endstops true // If true, axis won't move to coordinates less than HOME_POS.
#define max_software_endstops true  // If true, axis won't move to coordinates greater than the defined lengths below.
#define X_MAX_POS 230
#define X_MIN_POS 0
#define Y_MAX_POS 230
#define Y_MIN_POS 0
#define Z_MAX_POS 230
#define Z_MIN_POS 0
#define X_MAX_LENGTH (X_MAX_POS - X_MIN_POS)
#define Y_MAX_LENGTH (Y_MAX_POS - Y_MIN_POS)
#define Z_MAX_LENGTH (Z_MAX_POS - Z_MIN_POS)
#define MANUAL_X_HOME_POS 0
#define MANUAL_Y_HOME_POS 0
#define MANUAL_Z_HOME_POS 0
#define NUM_AXIS 4 // The axis order in all axis related arrays is X, Y, Z, E
#define HOMING_FEEDRATE {100*60, 100*60, 40*60, 0}  // set the homing speeds (mm/min)
#define DEFAULT_AXIS_STEPS_PER_UNIT   {80.0,80.0,200,327}  // default steps per unit for ultimaker2
#define DEFAULT_MAX_FEEDRATE          {300, 300, 40, 45}    // (mm/sec)
#define DEFAULT_MAX_ACCELERATION      {9000,9000,100,10000}    // X, Y, Z, E maximum start speed for accelerated moves. E default values are good for skeinforge 40+, for older versions raise them a lot.
#define DEFAULT_ACCELERATION          3000    // X, Y, Z and E max acceleration in mm/s^2 for printing moves
#define DEFAULT_RETRACT_ACCELERATION  3000   // X, Y, Z and E max acceleration in mm/s^2 for retracts
#define DEFAULT_XYJERK                20.0    // (mm/sec)
#define DEFAULT_ZJERK                 0.4     // (mm/sec)
#define DEFAULT_EJERK                 5.0    // (mm/sec)
#define FILAMANT_BOWDEN_LENGTH        840 // was 705 from factory
#define EEPROM_SETTINGS
#define EEPROM_CHITCHAT
#define PLA_PREHEAT_HOTEND_TEMP 180
#define PLA_PREHEAT_HPB_TEMP 70
#define PLA_PREHEAT_FAN_SPEED 0     // Insert Value between 0 and 255
#define ABS_PREHEAT_HOTEND_TEMP 240
#define ABS_PREHEAT_HPB_TEMP 100
#define ABS_PREHEAT_FAN_SPEED 0     // Insert Value between 0 and 255
#define SDSUPPORT // Enable SD Card Support in Hardware Console
#define ENABLE_ULTILCD2 //128x64 pixel display in the Ultimaker 2, with new menus. Note: For compiling with Arduino you need to remove the "SIGNAL(TWI_vect)" function from "libraries/Wire/utility/twi.c"
#define SOFT_PWM_SCALE 0
#define END_OF_PRINT_RETRACTION 20		// number of mm to retract when printer goes idle
#define END_OF_PRINT_RECOVERY_SPEED 5 	// speed to recover that assumed retraction at (mm/s)
#define PRIMING_MM3	50					// number of mm^3 of plastic to extrude when priming
#define PRIMING_MM3_PER_SEC 5			// Rate at which to prime head (in mm^3/s)
#define PRIMING_HEIGHT 20				// Height at which to perform the priming extrusions
#define LEVELING_OFFSET 0.1				// Assumed thickness of feeler gauge/paper used in leveling (mm)
#include "Configuration_adv.h"
#include "thermistortables.h"

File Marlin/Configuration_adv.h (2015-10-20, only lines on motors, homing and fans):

#define CONTROLLERFAN_PIN -1 //Pin used for the fan to cool controller (-1 to disable)
#define EXTRUDER_0_AUTO_FAN_PIN   -1
#define EXTRUDER_1_AUTO_FAN_PIN   -1
#define EXTRUDER_2_AUTO_FAN_PIN   -1
#define ENDSTOPS_ONLY_FOR_HOMING // If defined the endstops will only be used for homing
#define X_HOME_RETRACT_MM 7
#define Y_HOME_RETRACT_MM 7
#define Z_HOME_RETRACT_MM 7
#define QUICK_HOME  //if this is defined, if both x and y are to be homed, a diagonal move will be performed initially.
#define MICROSTEP1 LOW,LOW
#define MICROSTEP2 HIGH,LOW
#define MICROSTEP4 LOW,HIGH
#define MICROSTEP8 HIGH,HIGH
#define MICROSTEP16 HIGH,HIGH
#define MICROSTEP_MODES {16,16,16,1,1} // [1,2,4,8,16]
#define DIGIPOT_MOTOR_CURRENT {135,135,135,135,135} // Values 0-255 (RAMBO 135 = ~0.75A, 185 = ~1A)
#define DEFAULT_PWM_MOTOR_CURRENT {1200, 1200, 1500}

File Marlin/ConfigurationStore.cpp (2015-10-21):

#include "Marlin.h"
#include "planner.h"
#include "temperature.h"
#include "ultralcd.h"
#include "UltiLCD2.h"
#include "ConfigurationStore.h"

void _EEPROM_writeData(int &pos, uint8_t* value, uint8_t size)
{
    do
    {
        eeprom_write_byte((unsigned char*)pos, *value);
        pos++;
        value++;
    }while(--size);
}
#define EEPROM_WRITE_VAR(pos, value) _EEPROM_writeData(pos, (uint8_t*)&value, sizeof(value))
void _EEPROM_readData(int &pos, uint8_t* value, uint8_t size)
{
    do
    {
        *value = eeprom_read_byte((unsigned char*)pos);
        pos++;
        value++;
    }while(--size);
}
#define EEPROM_READ_VAR(pos, value) _EEPROM_readData(pos, (uint8_t*)&value, sizeof(value))
//======================================================================================




#define EEPROM_OFFSET 100


// IMPORTANT:  Whenever there are changes made to the variables stored in EEPROM
// in the functions below, also increment the version number. This makes sure that
// the default values are used whenever there is a change to the data, to prevent
// wrong data being written to the variables.
// ALSO:  always make sure the variables in the Store and retrieve sections are in the same order.
#define EEPROM_VERSION "V11"

#ifdef EEPROM_SETTINGS
void Config_StoreSettings()
{
  char ver[4]= "000";
  int i=EEPROM_OFFSET;
  EEPROM_WRITE_VAR(i,ver); // invalidate data first
  EEPROM_WRITE_VAR(i,axis_steps_per_unit);
  EEPROM_WRITE_VAR(i,max_feedrate);
  EEPROM_WRITE_VAR(i,max_acceleration_units_per_sq_second);
  EEPROM_WRITE_VAR(i,acceleration);
  EEPROM_WRITE_VAR(i,retract_acceleration);
  EEPROM_WRITE_VAR(i,minimumfeedrate);
  EEPROM_WRITE_VAR(i,mintravelfeedrate);
  EEPROM_WRITE_VAR(i,minsegmenttime);
  EEPROM_WRITE_VAR(i,max_xy_jerk);
  EEPROM_WRITE_VAR(i,max_z_jerk);
  EEPROM_WRITE_VAR(i,max_e_jerk);
  EEPROM_WRITE_VAR(i,add_homeing);
  #ifndef ULTIPANEL
  int plaPreheatHotendTemp = PLA_PREHEAT_HOTEND_TEMP, plaPreheatHPBTemp = PLA_PREHEAT_HPB_TEMP, plaPreheatFanSpeed = PLA_PREHEAT_FAN_SPEED;
  int absPreheatHotendTemp = ABS_PREHEAT_HOTEND_TEMP, absPreheatHPBTemp = ABS_PREHEAT_HPB_TEMP, absPreheatFanSpeed = ABS_PREHEAT_FAN_SPEED;
  #endif
  EEPROM_WRITE_VAR(i,plaPreheatHotendTemp);
  EEPROM_WRITE_VAR(i,plaPreheatHPBTemp);
  EEPROM_WRITE_VAR(i,plaPreheatFanSpeed);
  EEPROM_WRITE_VAR(i,absPreheatHotendTemp);
  EEPROM_WRITE_VAR(i,absPreheatHPBTemp);
  EEPROM_WRITE_VAR(i,absPreheatFanSpeed);
  #ifdef PIDTEMP
    EEPROM_WRITE_VAR(i,Kp);
    EEPROM_WRITE_VAR(i,Ki);
    EEPROM_WRITE_VAR(i,Kd);
  #else
		float dummy = 3000.0f;
    EEPROM_WRITE_VAR(i,dummy);
		dummy = 0.0f;
    EEPROM_WRITE_VAR(i,dummy);
    EEPROM_WRITE_VAR(i,dummy);
  #endif
  EEPROM_WRITE_VAR(i,motor_current_setting);
  #ifdef ENABLE_ULTILCD2
  EEPROM_WRITE_VAR(i,led_brightness_level);
  EEPROM_WRITE_VAR(i,led_mode);
  #else
  uint8_t dummyByte=0;
  EEPROM_WRITE_VAR(i,dummyByte);
  EEPROM_WRITE_VAR(i,dummyByte);
  #endif
  EEPROM_WRITE_VAR(i,retract_length);
  EEPROM_WRITE_VAR(i,retract_feedrate);
  char ver2[4]=EEPROM_VERSION;
  i=EEPROM_OFFSET;
  EEPROM_WRITE_VAR(i,ver2); // validate data
  SERIAL_ECHO_START;
  SERIAL_ECHOLNPGM("Settings Stored");
}
#endif //EEPROM_SETTINGS


#ifdef EEPROM_CHITCHAT
void Config_PrintSettings()
{  // Always have this function, even with EEPROM_SETTINGS disabled, the current values will be shown
    SERIAL_ECHO_START;
    SERIAL_ECHOLNPGM("Steps per unit:");
    SERIAL_ECHO_START;
    SERIAL_ECHOPAIR("  M92 X",axis_steps_per_unit[0]);
    SERIAL_ECHOPAIR(" Y",axis_steps_per_unit[1]);
    SERIAL_ECHOPAIR(" Z",axis_steps_per_unit[2]);
    SERIAL_ECHOPAIR(" E",axis_steps_per_unit[3]);
    SERIAL_ECHOLN("");

    SERIAL_ECHO_START;
    SERIAL_ECHOLNPGM("Maximum feedrates (mm/s):");
    SERIAL_ECHO_START;
    SERIAL_ECHOPAIR("  M203 X",max_feedrate[0]);
    SERIAL_ECHOPAIR(" Y",max_feedrate[1] );
    SERIAL_ECHOPAIR(" Z", max_feedrate[2] );
    SERIAL_ECHOPAIR(" E", max_feedrate[3]);
    SERIAL_ECHOLN("");

    SERIAL_ECHO_START;
    SERIAL_ECHOLNPGM("Maximum Acceleration (mm/s2):");
    SERIAL_ECHO_START;
    SERIAL_ECHOPAIR("  M201 X" ,max_acceleration_units_per_sq_second[0] );
    SERIAL_ECHOPAIR(" Y" , max_acceleration_units_per_sq_second[1] );
    SERIAL_ECHOPAIR(" Z" ,max_acceleration_units_per_sq_second[2] );
    SERIAL_ECHOPAIR(" E" ,max_acceleration_units_per_sq_second[3]);
    SERIAL_ECHOLN("");
    SERIAL_ECHO_START;
    SERIAL_ECHOLNPGM("Acceleration: S=acceleration, T=retract acceleration");
    SERIAL_ECHO_START;
    SERIAL_ECHOPAIR("  M204 S",acceleration );
    SERIAL_ECHOPAIR(" T" ,retract_acceleration);
    SERIAL_ECHOLN("");
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

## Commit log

2015-09-13 reverse feeder motor direction
    [Configuration.h]
2015-09-13 Increase motor current to 1450ma
    [Configuration_adv.h]
2015-09-17 updated stepper current
2015-10-15 Added document and parts
    [1306-Z2P-B hot end holder bottom.SLDPRT, 1306-Z2P-B hot end holder bottom.STEP, 1307-Z2P-B Hot End Holder Top.SLDPRT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]
2015-10-15 Increase stepper current to 1450ma
    [Configuration_adv.h]
2015-10-16 disable microstepping
    [Configuration_adv.h]
2015-10-20 Correct steps/mm to 330 for extruder
    [Configuration.h]
2015-10-20 new fan duct pic and retraction discussion
2015-10-20 added note on filament slip
2015-10-21 force use of default extruder steps/mm instead of EEPROM
2015-10-21 Drop steps/mm by 1%, fine tuning
    [Configuration.h]
2015-10-21 overwrite EEPROM steps/mm and current
